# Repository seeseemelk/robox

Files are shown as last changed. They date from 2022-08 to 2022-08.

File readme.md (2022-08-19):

# Robox project

## Project information

All info about the project can be found on the wiki. (work in progress)
This contains info on the hardware, firmware, manuals, ...
https://github.com/seeseemelk/robox/wiki

## Supporting the project

Do you like the project? Please consider supporting us! We are working on a V2 which will be easier to produce on our side and assemble on your side.



## Attiny source code

### Installation Microchip toolchain

https://www.microchip.com/en-us/tools-resources/develop/microchip-studio/gcc-compilers

linux: add path of extracted archive to your PATH
(e.g. in .bashrc: `export PATH="$PATH:/<path>/avr8-gnu-toolchain-linux_x86_64/bin"`)

add `/home/<user>/avr8-gnu-toolchain-linux_x86_64/avr/include` to C_INCLUDE_PATH

install package `avr-libc`
(```
/usr/lib/gcc/avr/5.4.0/../../../avr/bin/ld: cannot find crtattiny461a.o: No such file or directory
collect2: error: ld returned 1 exit status
make: *** [Makefile:48: bin/robox.elf] Error 1
```)

### Build source

```bash
$ make help
Targets:
  all       - (default) Builds the firmware. Same as the elf target
  bin       - Produces a bin file
  clean     - Cleans the compiled objects
  elf       - Produces an ELF file
  flash     - Flash the project onto a chip
  help      - Shows this help file
  hex       - Produces a hex file
  hex-text  - Produces an intel hex file
```

## FFT library
https://github.com/kosme/fix_fft

extra function anotations:
https://gist.github.com/Tomwi/3842231

## Owl

### Installation

1. Download from http://www.jtxp.org/tech/onewayloader_en.htm#download

1. check hash:
```bash
$ sha256sum owl.zip 
b97ae12d1bdd31152652383fb7a0708e94f02b179006a6694b1ff04fcfbaf0b5  owl.zip
```

### Usage

http://www.jtxp.org/tech/onewayloader_en.htm#quickstart

#### Add new target
(Make tailored OWL Firmware)

```bash
$ ./owl --device=tn461A --targetname=owl_robox --clock=8000 --rxport=B6

SINGLE TARGET MAKE MODE

MAKE TARGET FIRMWARE

RXPORT NORMAL LOGIC
TXPORT NORMAL LOGIC
MODIFY PORT ASSIGNMENTS
ALL RESET SOURCES ENABLED
MODIFY CLOCK REFERENCE FOR ATTINY

TARGET LOADER DATA

FILEPATH 	: ./targets/owl_robox.hex
DEVICENAME	: tn461
SIGNATURE	: 1E9208
FW BUILD DATE	: 20210223
EEPROMSIZE	: 256
FLASHSIZE	: 4096
PAGESIZE	: 64
BOOTSIZE 	: 512
APPFLASH	: 3580
RXPORT   	: B6
TXPORT   	: --
CLOCK    	: 8000
CIPHER   	: RST
KEY      	: 6A352411627D7E31...
RESET SOURCES	: 1111 W B E P 
BAUD RANGE	: 800...16000
DEFAULT BAUD	: 9600
DEFAULT TIMEOUT	: 1.00
DEFAULT IP	: 1.00
DEFAULT OP	: 0.10

NEW TARGET FILE SUCCESSFULLY SAVED.
```

#### Create audio file

```bash
$ ./owl --targetname=owl_robox --flashfile=../robox/bin/robox.hex --audioexport

TRANSMISSION MODE

TARGET LOADER DATA

FILEPATH 	: ./targets/owl_robox.hex
DEVICENAME	: tn461
SIGNATURE	: 1E9208
FW BUILD DATE	: 20210223
EEPROMSIZE	: 256
FLASHSIZE	: 4096
PAGESIZE	: 64
BOOTSIZE 	: 512
APPFLASH	: 3580
RXPORT   	: B0
TXPORT   	: --
CLOCK    	: 4000
CIPHER   	: RST
KEY      	: 34FB4E1420DF639C...
RESET SOURCES	: 1111 W B E P 
BAUD RANGE	: 400...8000
DEFAULT BAUD	: 4800
DEFAULT TIMEOUT	: 1.00
DEFAULT IP	: 1.00
DEFAULT OP	: 0.10

MAKE OWL TRANSMISSION

FILEPATH	: ./transmissions/20220305__robox_owl_robox.owl
BAUDRATE	: 4800
INTPREAMBLE	: 1.00
OUTPREAMBLE	: 0.10
[S1] AUTH	: 76BA4C20E8736540D0DCF76EB228B3B0  /  3
[S2] EEPROM	: 1053021E6E3BE4A352B2886D64B3C638  /  2
[S3] FLASH	: 3DD6527248B6ECDCE2501FA8F9886A9D  /  6
BYTES TOTAL	: 1112
DURATION   	: 2.32

EXPORT TO AUDIO FILE (PCM 2-CH 16 BIT 44.1K)

SOURCE FILE	: ./transmissions/20220305__robox_owl_robox.owl
WAVFILENAME	: ./transmissions/20220305__robox_owl_robox.owl.wav
WAVFILESIZE	: 408364
NOMINAL BAUD	: 4800
```

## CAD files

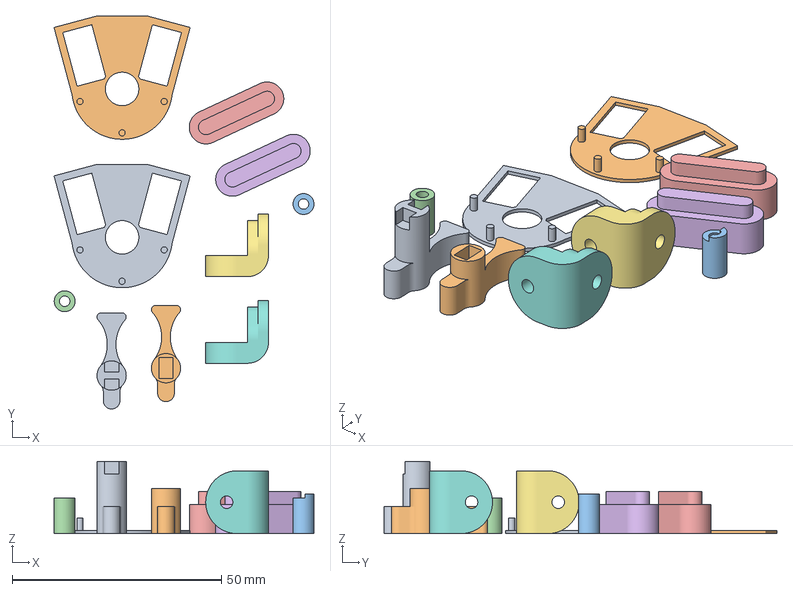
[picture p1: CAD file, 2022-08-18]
documentation/3D-printing/full set.3mf
62.2 x 94.0 x 17.3 mm
right ear holder
left ear holder
pcb spacer 1
pcb spacer 2
LED-holder
bracket
micro switch holder

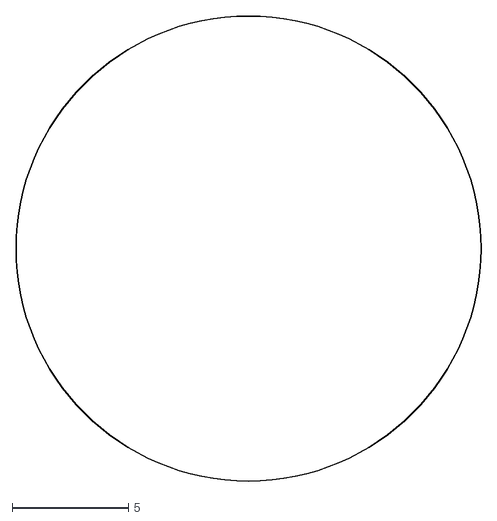
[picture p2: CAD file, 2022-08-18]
documentation/laser cutting/full set.dxf
20.0 x 20.0

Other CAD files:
documentation/laser cutting/qr-code.dxf

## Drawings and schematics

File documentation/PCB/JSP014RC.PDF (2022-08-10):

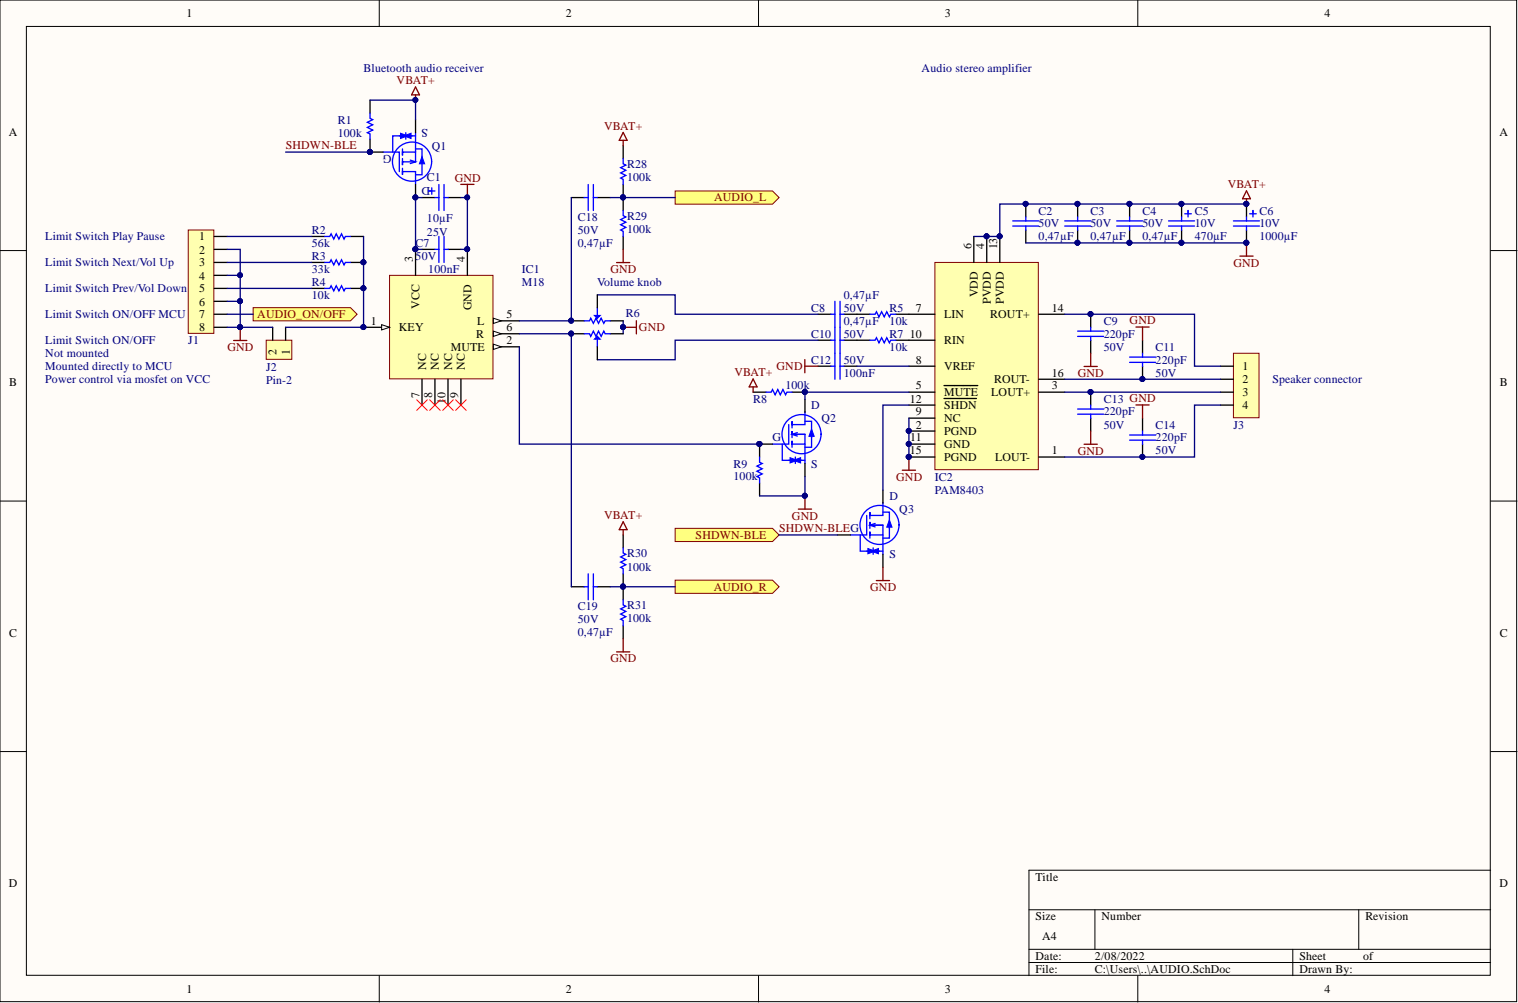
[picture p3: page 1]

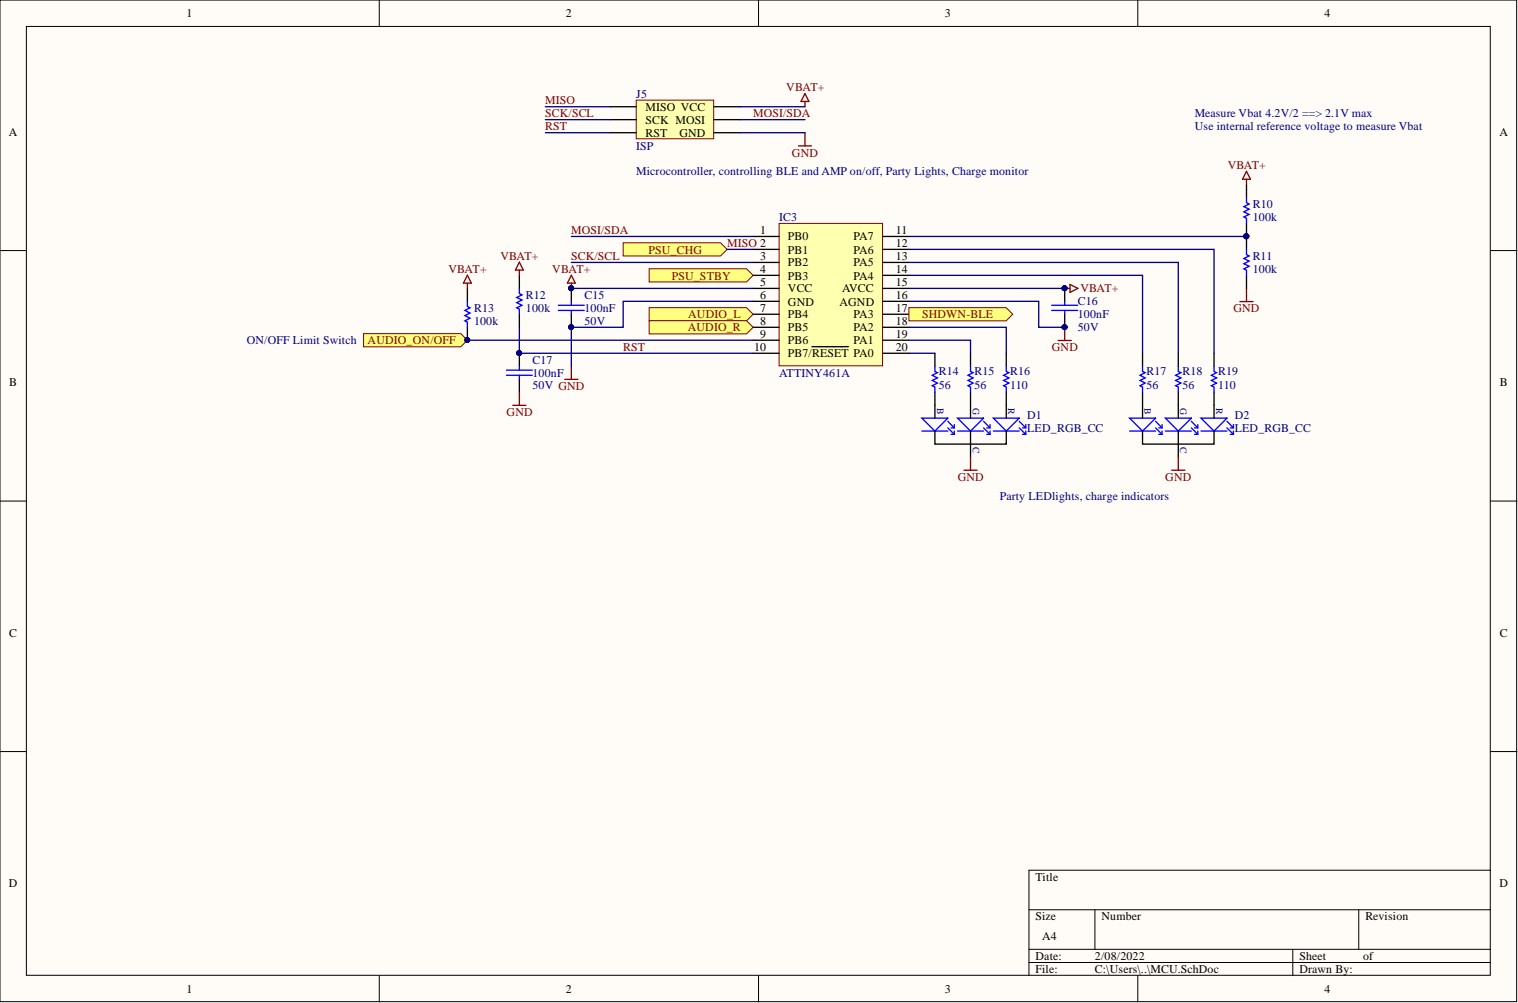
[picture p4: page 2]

Measure Vbat 4.2V/2 ==> 2.1V max
Use internal reference voltage to measure Vbat

Microcontroller, controlling BLE and AMP on/off, Party Lights, Charge monitor

ON/OFF Limit Switch

Party LEDlights, charge indicators

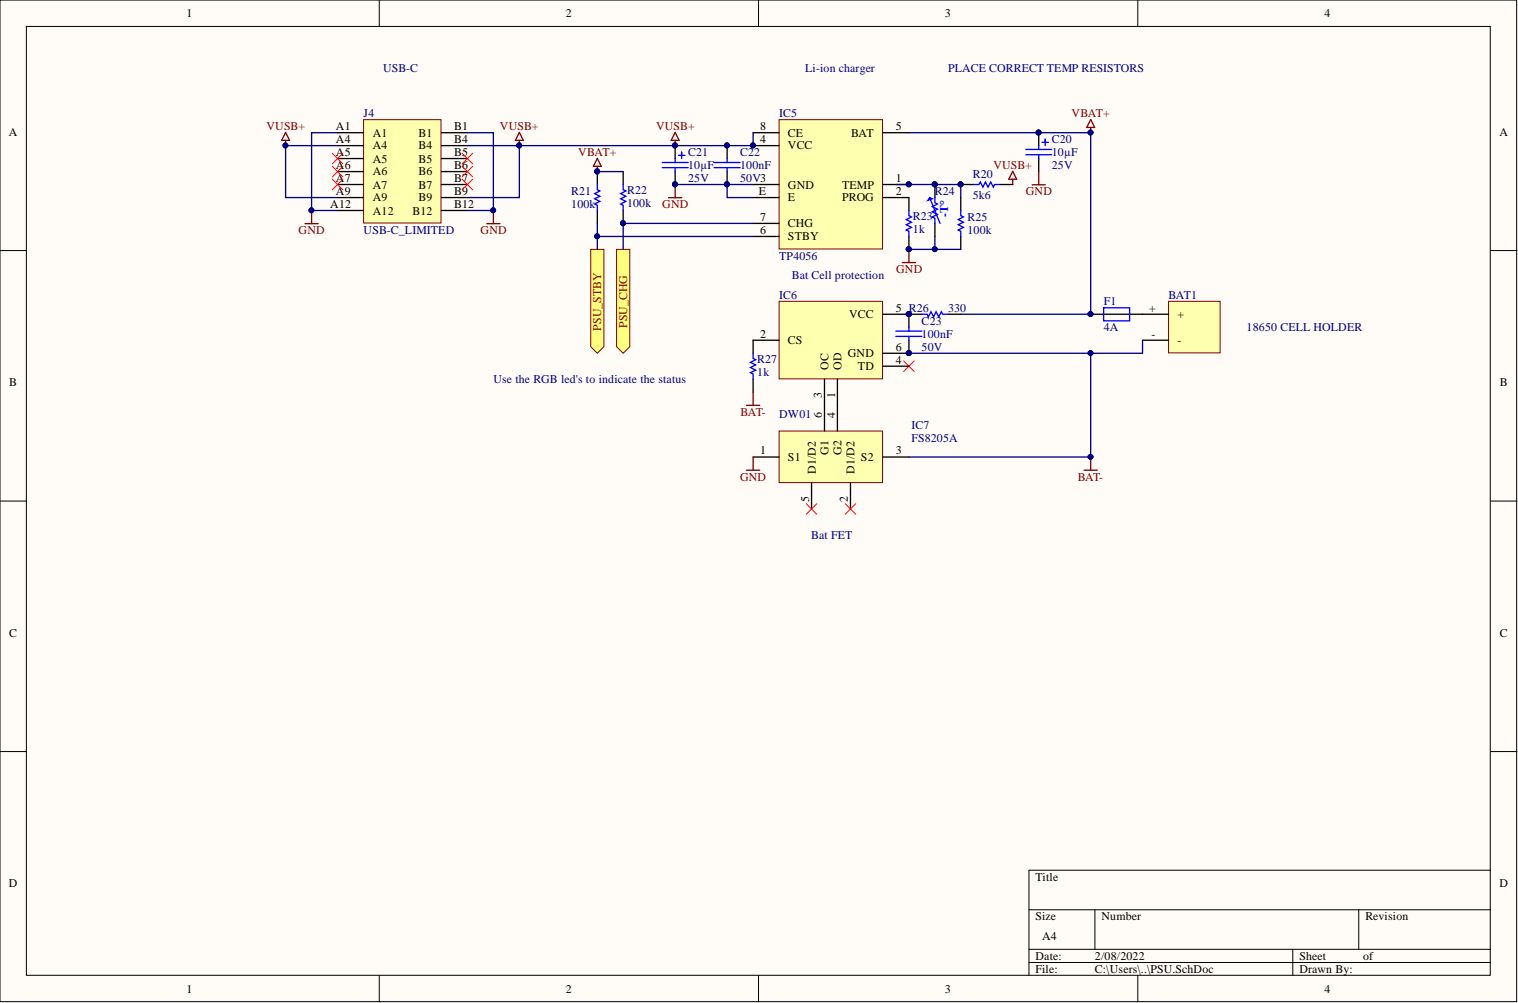
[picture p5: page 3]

5 0 V
4 | IC7 FS8 2 0 5 A

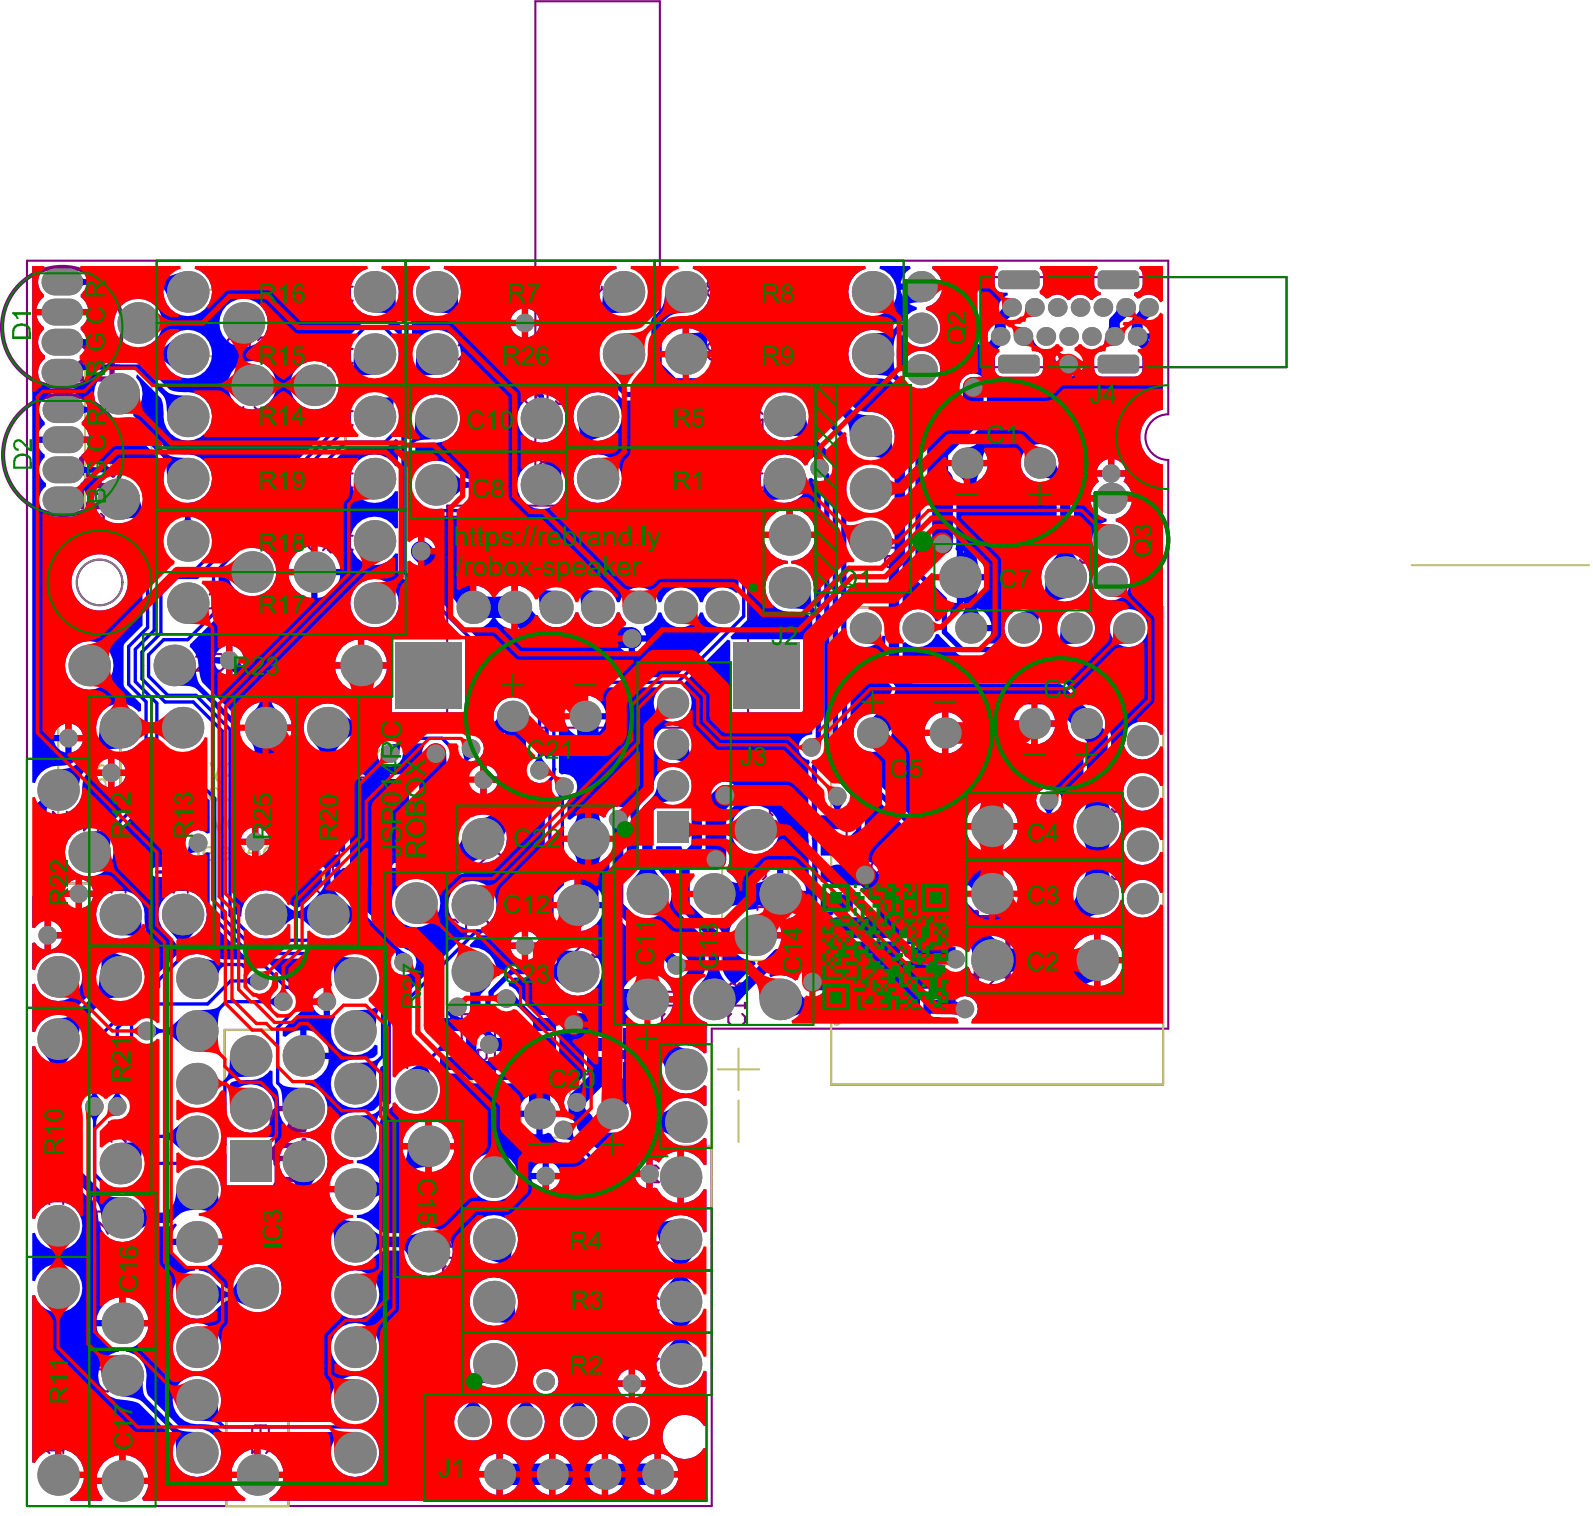
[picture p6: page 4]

# Paragon Electronics

Project Title: | JSP021RC.PrjPCB | Number of PCB's | 1
BOM Revision: | REV1
Date: | 30/10/2019
Designator | #Column Name Error: #Column Name | Error:value | Description | #Column Name Error:manufacturer_ ref | manufacturer | supplier_1 | supplier_1_partnum ber | #Column Name Error:price | Quantity | Cost | Quantity for all PCB's | Total Cost
C5 | | | CAP ALUM 470UF 20% 10V TH | | AISHI(Aihua Group) | lcsc | C2924460 | | 1 | 0 | 1 | 0
C9, C11, C13, C14 | | | CAP CER TH 100nF X7R 50V | | WMEC | lcsc | C2905888 | | 4 | 0 | 4 | 0
Q1 | | | MOSFET P-CH 60V 17A TO-220AB | | HUASHUO | lcsc | C2903571 | | 1 | 0 | 1 | 0
R14, R15, R17, R18 | | | RES TH 56 OHM 5% 1/8W | | VO | lcsc | C2896859 | | 4 | 0 | 4 | 0
R2 | | | RES TH 56k OHM 5% 1/4W | | VO | lcsc | C2896856 | | 1 | 0 | 1 | 0
R26 | | | RES TH 330 OHM 5% 1/4W | | VO | lcsc | C2894590 | | 1 | 0 | 1 | 0
R23, R27 | | | RES TH 1k OHM 5% 1/4W | | VO | lcsc | C2894570 | | 2 | 0 | 2 | 0
R3 | | | RES TH 33k OHM 5% 1/4W | | VO | lcsc | C2894551 | | 1 | 0 | 1 | 0
R4, R5, R7 | | | RES TH 10k OHM 5% 1/4W | | VO | lcsc | C2894537 | | 3 | 0 | 3 | 0
R1, R8, R9, R10, R11, R12, R13, R21, R22, R25, R28, R29, R30, R31 | | | RES TH 100k OHM 5% 1/4W | | VO | lcsc | C2894520 | | 14 | 0 | 14 | 0
C1, C20, C21 | | | CAP ALUM 10UF 20% 25V TH | | Yunxing | lcsc | C2841587 | | 3 | 0 | 3 | 0
D1, D2 | | | LED (RGB) | | TOGIALED | lcsc | C2837020 | | 2 | 0 | 2 | 0
IC7 | | | IC MOSFET Array 3A | | TECH PUBLIC | lcsc | C2830320 | | 1 | 0 | 1 | 0
J4 | | | USB TYPE C , RECEPTACLE, R/A | | G-Switch | lcsc | C2762981 | | 1 | 0 | 1 | 0
C2, C3, C4, C8, C10, C18, C19 | | | CAP CER TH 0.47µF X7R 50V | | Dersonic | lcsc | C2761753 | | 7 | 0 | 7 | 0
R16, R19 | | | RES TH 110 OHM 1% 1/8W | | Huaxing Mechanical-Elec. | lcsc | C713899 | | 2 | 0 | 2 | 0
C7, C12, C15, C16, C17, C22, C23 | | | CAP CER TH 100nF X7R 50V | | FH | lcsc | C385200 | | 7 | 0 | 7 | 0
R24 | | | THERMISTOR NTC 10KOHM 3435K BEAD | | Nanjing Shiheng Elec | lcsc | C123389 | | 1 | 0 | 1 | 0
C6 | | | CAP ALUM 1000UF 20% 10V TH | | AISHI(Aihua Group) | lcsc | C105310 | | 1 | 0 | 1 | 0
R20 | | | RES TH 4k12 OHM 1% 1/4W | | UNI-ROYAL(Uniroyal Elec) | lcsc | C58603 | | 1 | 0 | 1 | 0
IC2 | | | 3W x 2 RL=4Ω 2.5V ~ 5.5V (stereo) Class D SOIC-16 Audio Power OpAmps | | Diodes Incorporated | lcsc | C17337 | | 1 | 0 | 1 | 0
IC6 | | | IC Battery Management IC | | Fortune Semicon | lcsc | C14213 | | 1 | 0 | 1 | 0
Q2, Q3 | | | MOSFET N-CH 60V 0.2A TO-92 | | Changjiang Electronics Tech (CJ) | lcsc | C9114 | | 2 | 0 | 2 | 0
BAT1 | | | 18650 single cell Battery holder | | GTIWUNG | amazon | B08CY56M98 | | 1 | 0 | 1 | 0
J3 | | | CONN HEADER VERT 4POS 2MM | | JST Sales America Inc. | digikey | B4B-PH-K(LF)(SN)-ND | | 1 | 0 | 1 | 0
IC3 | | | IC MCU 8BIT 4KB FLASH 20DIP | | Microchip Technology | digikey | ATTINY461A-PU-ND, 2057-ICS-320-T-ND | | 1 | 0 | 1 | 0
J1 | | | CA 200MM 08 POS. MOW-PB M-M VALU | | TE Connectivity AMP Connectors | digikey | A123436-ND | | 1 | 0 | 1 | 0
IC1 | | | M18 Bluetooth 4.2 Audio-receiver Module Lossless | | | banggood | 1527332 | | 1 | 0 | 1 | 0
R6 | | | POT 10K OHM 1/20W PLASTIC LINEAR | | TT Electronics/BI | digikey | 987-1296-ND | | 1 | 0 | 1 | 0
F1 | | | FUSE BOARD MOUNT 4A 32VDC 0603 | | Vishay Beyschlag/Draloric/BC Components | digikey | 749-MFU0603FF04000P 500CT-ND | | 1 | 0 | 1 | 0
IC5, J2, J5 | | | [NoValue], 'CONN 2 PIN SOLDER PADS, CONN 6 PIN SOLDER PADS FOR ISP | | | | | | 3 | 0 | 3 | 0
| | | | | | | | 0 | 0 | 0 | 72 | 0

# Belgium

## Components

# BILL OF MATERIALS

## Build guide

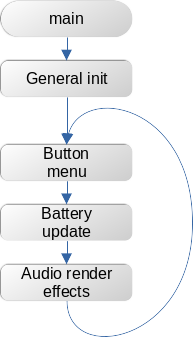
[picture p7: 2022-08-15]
documentation/Instruction manuals/main.png

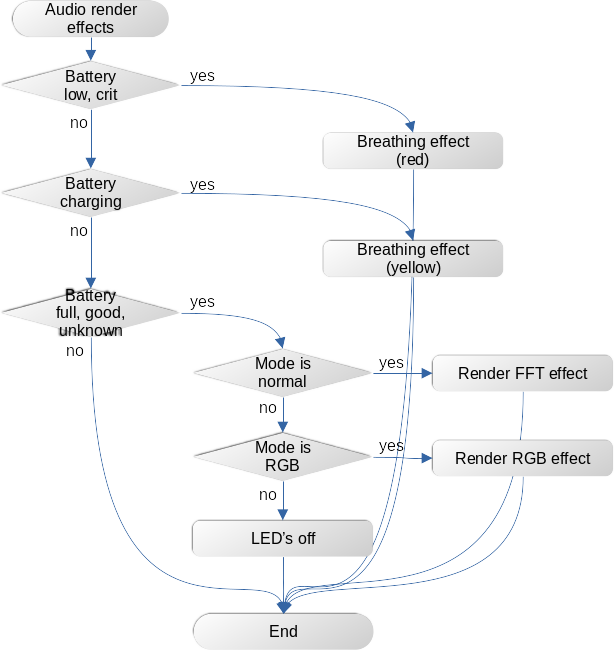
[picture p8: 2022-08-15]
documentation/Instruction manuals/audio_render.png

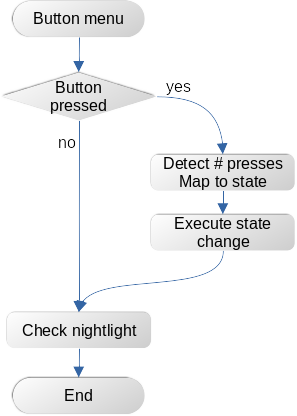
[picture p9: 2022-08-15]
documentation/Instruction manuals/button.png

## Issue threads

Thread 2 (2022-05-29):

Night light

seeseemelk, 2022-05-29:
Add support for:

 - A changing colour night light
 - A constant light
 - A way to change the brightness

parsupo, 2022-08-18:
changing color night light was implemented,
constant light was not implemented (replaced by disco mode and lights off)
brightness control was not implemented (too difficult to setup with only one button)

Closed 2022-08-18.

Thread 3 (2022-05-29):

Better battery life

seeseemelk, 2022-05-29:

parsupo, 2022-08-18:
was fixed over several fw-versions. a lifespan of 2y on a full battery is possible now.

Closed 2022-08-18.

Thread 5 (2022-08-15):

Behuizing zelf laser cutten / Laser cut housing

tomvanbraeckel, 2022-08-15:
(English below)

Hoi, wij waren vorig weekend op Fri3D camp 2022 maar de Bluetooth sessie zat al veel op voorhand volzet...

We zouden het graag zelf maken maar vinden op deze github de behuizing niet terug en het was net de behuizing die we zo leuk vonden, met dat robot gezichtje :-)

Zouden jullie de behuizing online kunnen zetten? Of staat ze al online en hebben we erover gekeken?

Alvast hartelijk bedankt!

PS: zet er gerust een donatie adres bij :-)

***

Hi, we were at Fri3D camp 2022 last weekend but the Bluetooth session was full way in advance...

We would love to make it ourselves but can't find the housing on this github and it was especially the housing which we liked so much, with that robot face :-)

Could you please put the housing online? Or is it already online and we've just overlooked it?

Thanks in advance!

PS: feel free to add a donation address :-)

WouterVandeWiele, 2022-08-17:
Goed om ons er aan te herinneren. We zullen de lasercut files, alsook de 3D geprinte onderdelen (voor de oogjes, micro switches en montage van de PCB en behuizing, in de loop van deze week online zetten.

tomvanbraeckel, 2022-08-18:
Dat is super goed nieuws, bedankt!

parsupo, 2022-08-18:
ze staan allemaal online denk ik:
[hw+3D-printing+laser-cutting-files](https://github.com/seeseemelk/robox/wiki/Hardware-description)

WouterVandeWiele, 2022-08-18:
Goed nieuw: de files staan nu in de documentation folder:
https://github.com/seeseemelk/robox/tree/master/documentation
* * *
3D print files and lastercut files are now available

tomvanbraeckel, 2022-08-19:
Perfect! Ik heb ze geimporteerd in Freecad en een extrude gedaan, zo kan ik ze 3D printen in plaats van te cutten ;-)

Nog 1 vraagje: hoe dik moet het gelasercut (of geextrude) worden? 3mm? 4mm?

parsupo, 2022-08-19:
Ik heb ook nog een step file van het volledige model gepusht. Dat is misschien gemakkelijker om de zijkant te printen. De triplex was 3mm dik maar dit varieerde soms tot 3.5mm. De lasercut files printen en plooien kan tricky zijn.

tomvanbraeckel, 2022-08-19:
Dat 3D model is geweldig, inderdaad ideaal, nogmaals bedankt!

parsupo, 2022-08-19:
Voor donaties hebben we nu ook ondersteuning toegevoegd. Uiteraard volledig vrijblijven.
[robox wiki main page](https://github.com/seeseemelk/robox/wiki)

tomvanbraeckel, 2022-08-19:
Done!

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

parsupo, 2022-08-19:
Many thanks!

Closed 2022-08-18.

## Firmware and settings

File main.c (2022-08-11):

#include "adc.h"
#include "audio.h"
#include "battery.h"
#include "button.h"
#include "led.h"
#include "power.h"
#include "defs.h"
#include "timer1.h"

#include <avr/sleep.h>
#include <avr/interrupt.h>
#include <util/delay.h>

#include <avr/sleep.h>

void general_init()
{
	cli();
	led_init();
	power_init();
	adc_init();
	battery_init();
	button_init();
	audio_init();

	wakey_wakey();
	setup_beat_detection_counter();

	SET_BIT(MCUCR, PUD);	// disable pull-ups
	SET_BIT(MCUCR, BODS);	// disable BOD
	SET_BIT(MCUCR, BODSE);

	CLEAR_BIT(WDTCR, WDE);	// disable watchdog
	SET_BIT(WDTCR, WDCE);
	sei();
}

/* main test audio and led render*/
int main()
{
	general_init();

	while (1)
	{
		button_menu();
		battery_update();
		audio_render_effects();
	}
}

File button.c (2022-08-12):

#include "button.h"

#include "adc.h"
#include "config.h"
#include "defs.h"
#include "power.h"
#include "led.h"
#include "audio.h"
#include "timer1.h"

#include <avr/io.h>
#include <avr/interrupt.h>
#include <avr/sleep.h>
#include <avr/power.h>

#define ENABLE_ON_INTERRUPT   SET_BIT(GIMSK, INT0)   //Enable External Interrupts Pin change
#define DISABLE_ON_INTERRUPT  CLEAR_BIT(GIMSK, INT0)

volatile GlobalModus global_modus = mapper_normal_mode;
volatile u16 night_light_counter = 0;
volatile u32 press_sequence = 0U;
volatile u32 press_mask = 0U;

/**
 * @brief Initialisation function for the mcu on / off button and INT0 interrupt.
 *
 */
void button_init()
{
	DDRB &= ~(1 << 6);	// configre PB6 as an input

	// ENABLE_ON_INTERRUPT;
	// level interrupt INT0 (low level)
    MCUCR &= ~((1 << ISC01) | (1 << ISC00));
}

/**
 * @brief Function to be called when the interupt awakes the mcu from sleeping.
 * It will powerup all mcu modules + bluetooth module and amp.
 *
 */
void wakey_wakey()
{
	// CLEAR_BIT(CLKPR, CLKPS3);
	// SET_BIT(CLKPR, CLKPCE);

	// power up modules on mcu
	power_adc_enable();
	power_timer1_enable();
	power_timer0_enable();
	power_usi_enable();
	adc_init();	// assuming adc is still configured, make adc enable and disable functions
	power_enable_ble();

	// toggle_music_only = true;
	// toggle_nightlight = false;

	// led_set_full(0xFF);

	// Digital Input (buffer) Disable Registers
	// DIDR0 &= ~(MASK(ADC6D) | MASK(ADC5D) | MASK(ADC4D) | MASK(ADC3D) | MASK(AREFD) | MASK(ADC2D) | MASK(ADC1D) | MASK(ADC0D));
	// DIDR1 &= ~(MASK(ADC10D) | MASK(ADC9D) | MASK(ADC8D) | MASK(ADC7D));
}

/**
 * @brief Function to be called when the off command is given.
 * Places the mcu and oher components in low power mode.
 *
 */
void nap_time()
{
	// set lower clock speed
	// SET_BIT(CLKPR, CLKPS3);
	// SET_BIT(CLKPR, CLKPCE);

	power_disable_ble();
	led_set_full(0x00);

	// power down modules on mcu
	power_adc_disable();
	power_timer1_disable();
	power_timer0_disable();
	power_usi_disable();
	// DDRA = 0;
	// DDRB = 0;


	// Digital Input (buffer) Disable Registers
	// DIDR0 |= (MASK(ADC6D) | MASK(ADC5D) | MASK(ADC4D) | MASK(ADC3D) | MASK(AREFD) | MASK(ADC2D) | MASK(ADC1D) | MASK(ADC0D));
	// DIDR1 |= (MASK(ADC10D) | MASK(ADC9D) | MASK(ADC8D) | MASK(ADC7D));
}

/**
 * @brief Call to place the MCU itself in a low power mode.
 * Be sure to configure an interupt that can wake the MCU from the "Power Down"
 * sleep mode.
 *
 */
void enter_deepsleep()
{
	global_modus = mapper_shutdown;
	disable_timer1();
	ENABLE_ON_INTERRUPT;
	DIDR0 = MASK(AREFD);
	adc_stop();
	set_sleep_mode(SLEEP_MODE_STANDBY);
	sleep_bod_disable();
	sleep_enable();
	nap_time();
	sei();
	sleep_cpu();
}

/**
 * @brief Function that returns only if the button is released (after being pressed down)
 * Also does some debouncing.
 *
 * @return u16
 */
static void wait_until_depressed()
{
	u8 count = 0;
	while (count < 0xFF)
	{
		if (button_is_pressed())
			count = 0;
		else
			count++;
	}
}

/**
 * @brief Detection mechanism long and x-amount of short presses
 *
 * @return MenuState
 */
ButtonPressPattern button_press_menu()
{
	ButtonPressPattern state = press_nothing;
	u8 short_presses = 0;

	cli();
	press_sequence = 0;
	press_mask = 0b1;

	setup_button_menu();
	sei();
	while (press_mask > 0) led_set_full(0x44);
	cli();

	led_set_full(0x00);

	if (button_is_pressed())
		state = press_long;
	else
	{
		for (u16 i = 0; i<(32-4); i++)
		{
			if (((press_sequence >> i) & 0xF) == 0b0011)
				short_presses++;
		}

		switch (short_presses)
		{
		case 1:
			state = press_1_short;
			break;
		case 2:
			state = press_2_short;
			break;
		default:
			state = press_nothing;
			break;
		}
	}

	return state;
}

void modus_mapper(ButtonPressPattern state)
{
	u8 color = 0;
	switch (state)
	{
	case press_long:
		global_modus = mapper_shutdown;
		// red + white
		color = MASK(4) | MASK(2) | MASK(1) | MASK(0);
		break;

	case press_1_short:
		if (global_modus == mapper_normal_mode)
		{
			global_modus = mapper_music_only;
			// blue + white
			color = MASK(6) | MASK(2) | MASK(1) | MASK(0);
		}
		else if (global_modus == mapper_music_only)
		{
			global_modus = mapper_music_rgb;
			// light blue + white
			color = MASK(6) | MASK(5) | MASK(2) | MASK(1) | MASK(0);
		}
		else
		{
			global_modus = mapper_normal_mode;
			// green + white
			color = MASK(5) | MASK(2) | MASK(1) | MASK(0);
		}
		break;

	case press_2_short:
		if (global_modus == mapper_normal_mode)
		{
			global_modus = mapper_music_night_light;
			// yellow + white
			color = MASK(5) | MASK(4) | MASK(2) | MASK(1) | MASK(0);
		}
		else if (global_modus == mapper_music_night_light)
		{
			global_modus = mapper_night_light;
			// purple + white
			color = MASK(6) | MASK(4) | MASK(2) | MASK(1) | MASK(0);
		}
		else
		{
			global_modus = mapper_normal_mode;
			// green + white
			color = MASK(5) | MASK(2) | MASK(1) | MASK(0);
		}
		break;

	default:
		break;
	}

	if (color != 0)
	{
		wait_until_depressed();
		led_set_full(color);

		setup_25ms_interrupt();
		sei();
		while(counter_25ms < WAIT_1S);
		cli();
	}

	led_set_full(0x00);
}

/**
 * @brief Function to be used in the main program loop.
 * Checks if on / off button is pressed by polling it.
 * If pressed configure the MCU to go in sleep mode.
 *
 */
void button_menu()
{
	cli();

	if (button_is_pressed())
	{
		disable_timer1();
		modus_mapper(
			button_press_menu()
		);
		disable_timer1();

		switch (global_modus)
		{
			case mapper_normal_mode:
				wakey_wakey();
				setup_beat_detection_counter();
				break;

			case mapper_shutdown:
				// going to sleep
				enter_deepsleep();
				break;

			case mapper_night_light:
				night_light_counter = 0;

				setup_25ms_interrupt();

				// disable audio
				power_disable_ble();
				break;

			case mapper_music_night_light:
				night_light_counter = 0;

				setup_25ms_interrupt();

				// disable audio
				power_enable_ble();
				break;

			case mapper_music_rgb:
				setup_25ms_interrupt();

				// enable audio
				power_enable_ble();
				break;

			case mapper_music_only:
				led_set_full(0x00);

				// disable audio
				power_enable_ble();
				break;

			default:
				break;
		}
	}

	// nightlight sleep check
	if (night_light_counter >= WAIT_15M)
	{
		if ((global_modus == mapper_night_light) || (global_modus == mapper_music_night_light))
			enter_deepsleep();
	}

	sei();
}

/**
 * @brief Construct a new ISR object
 * Interrupt routine when the MCU wakes up from an on / off button press.
 *
 */
ISR(INT0_vect)
{
	DISABLE_ON_INTERRUPT;
	sleep_disable();
	wakey_wakey();
	setup_beat_detection_counter();
	global_modus = mapper_normal_mode;

	wait_until_depressed();
}


/**
 * @brief Poll manually if button is pressed. (active low)
 *
 * @return bool, true if pressed down, false if not pressed.
 */
bool button_is_pressed()
{
#ifdef INVERT_IO
	return TEST_BIT_SET(PINB, 6);
#else
	return TEST_BIT_CLEAR(PINB, 6);
#endif
}
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

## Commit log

2022-05-24 Add support for inverted leds
    [button.c, led.c]
2022-05-25 Initial battery stuff
2022-05-25 testing interrupt
2022-05-26 Can detect battery level
2022-05-26 Enter sleep mode on button press.
2022-05-26 Exit from sleep on button press
2022-05-26 Enter a low power when going to sleep
2022-05-26 Enter a low power when going to sleep + De-bounce push button for button polling and interrupt
2022-05-27 tesing beat detection (refresh every 4Hz)
2022-05-27 Probably working battery code
2022-05-27 Add crit battery warning
2022-05-27 try extra power saving functions
2022-05-28 atempt to reduce power in sleep mode
2022-05-28 Add LED brightness scaling
2022-06-14 Improved low power support
2022-06-15 test and fix deep sleep wake up
    [button.c]
2022-06-16 Fixed some small bugs
    [button.c, led.c]
2022-07-18 Voltage gating
2022-07-19 Add battery debounce
2022-07-22 button menu attempt 1
2022-07-22 multifunctional button working
2022-07-31 attempt 6 to integrate in main (fix timer settings, add beat detection back)
    [button.c, led.c, main.c]
2022-08-03 adding extra abstraction layer for button press menu
2022-08-05 fix button munu refactor
    [button.c, led.c, main.c]
2022-08-05 try to fix battery glitches
    [button.c]
2022-08-07 fix charging animation staying on when charging is done
2022-08-07 fix battery state gliches when voltage dips momentarily
    [led.c]
2022-08-07 fix timeout nightlight;, improve beat detection
    [button.c, led.c]
2022-08-10 fix battery state glitches causing fft to flicker.
    [button.c, main.c]
2022-08-10 pcb documentation + files, building manual (dutch), demo
    pcb documentation + files, building manual (dutch), demo video's about functionality
    [AUDIO.SchDoc, JSP014RC.PrjPCB, MCU.SchDoc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]
2022-08-15 set fusebits when flashing the mcu
2022-08-15 fix name of battery image
2022-08-18 added laser cut files and 3D-printing files
    added laser cut files and 3D-printing files
    [full set.3mf, full set.dxf, qr-code.dxf]
